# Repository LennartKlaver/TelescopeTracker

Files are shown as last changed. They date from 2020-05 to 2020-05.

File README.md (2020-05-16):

# TelescopeTracker

_**Please note: this is work in progress and not a finished product**_

The goal of this project is to make a telescope guiding camera work with PHD2 or alike by wifi.

My idea is to use the new Raspbery Pi HQ camera module and fit it into a 1.25inch eyepiece holder.
The camera can stream the video to the pc using the network, which can be converted to a virtual webcam device which we can open in PHD2.

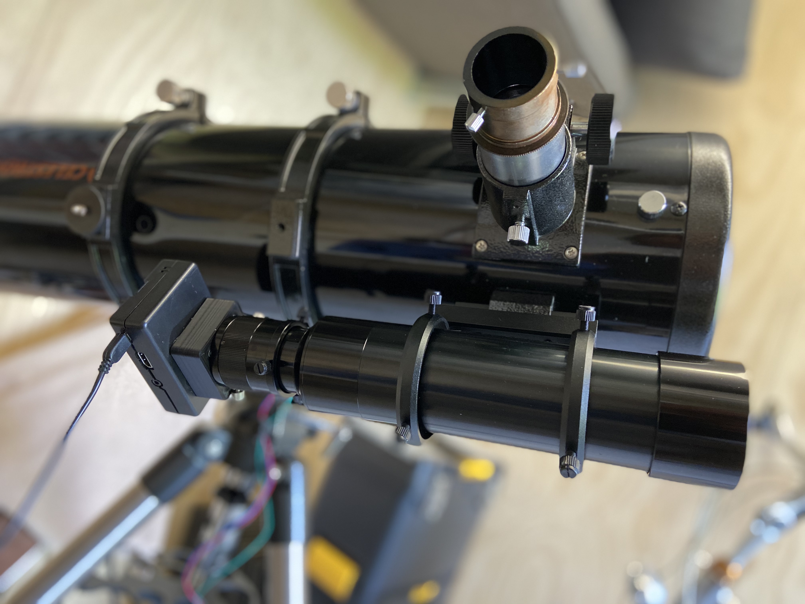
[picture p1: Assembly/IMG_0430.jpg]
Image of the telescope


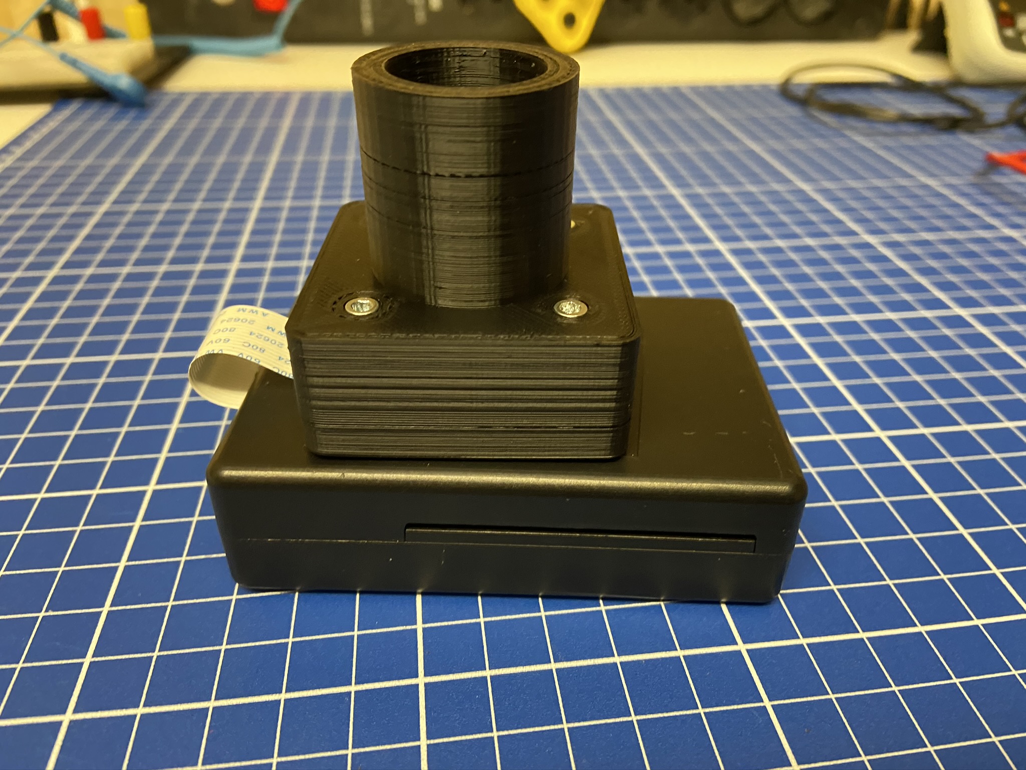
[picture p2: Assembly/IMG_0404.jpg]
Image of the camera assembly


# Parts
* A 3d printed camera mount for the eyepiece.
* A Raspberry Pi. https://www.raspberrypi.org/products/
* A nice casing to fit the raspberry in.
* A Raspberry Pi hq camera: https://www.raspberrypi.org/products/raspberry-pi-high-quality-camera/
* 4 M3x25 hexagon machine screw with cilinder head.
* 8 M3 nuts (I used self locking nuts to make sure they do not come loose).

# Instructions

## Assembly
1. Download the STL file and 3d print it.
2. From the camera, remove the small part that can be used to screw the cam on a mount. It is fixed by 2 hex bolts.
3. Check if the camera fits your print.
4. Place the printed part on top of the raspberry casing and mark the 4 holes.
	Please pick a spot where there are no components underneath (not to close to the usb ports).
	Also take note for the orientation of the ribbon cable. My casing had some room above the usb port so I guided the cable to that side.
5. Drill the mounting holes with a 3mm drill (remove the raspberry pi from the casing before drilling ... ).
6. Screw 4 M3x25 hexagon screws in the printed casing.
7. Push the camera module gently in its place. Sometimes it fits perfect, sometimes you have to turn the screws. Please apply proper ESD protection
8. Fixate the camera with 4 nuts..
9. Place the camera on top of the raspberry casing, do not forget the cable.
10. File a small gap to fit the ribbon cable inside the raspi casing.
11. Close the raspberry pi casing.
12. Place the camera on your telescope and power it up.

## Software
From here I assume you know a little bit about Raspberry Pi's. I used a headless setup and use SSH to communicate with the platform.
I connected the camera with my wifi and then used the steps below.
1. To enable the camera follow these steps: https://www.raspberrypi.org/documentation/usage/camera/
2. Check if the camera works by a call from the terminal: `raspistill -o testshot.jpg`
	Please note: if the image looks blurry, you need to focus the telescope/camera.
3. Install the RPi web interface for easy looking by browsing to the RasPi IP address: https://elinux.org/RPi-Cam-Web-Interface
	1. `sudo apt-get update`
	2. `sudo apt-get dist-upgrade`
	3. `sudo apt-get install git` 
	4. `git clone https://github.com/silvanmelchior/RPi_Cam_Web_Interface.git`
	5. `cd RPi_Cam_Web_Interface`
	6. `./install.sh`
	7. Browse to the Raspberry Pi's ip address and see the camera output.
	
To be continued....

# Development
## Finished
* Hardware design finished.
* Casing design finished.
* The camera mount fits the eyepiece.
* The camera works.
* The Raspberry Pi streams video with minimal delay.

## Next step
* Integrate the stream into windows cam system.

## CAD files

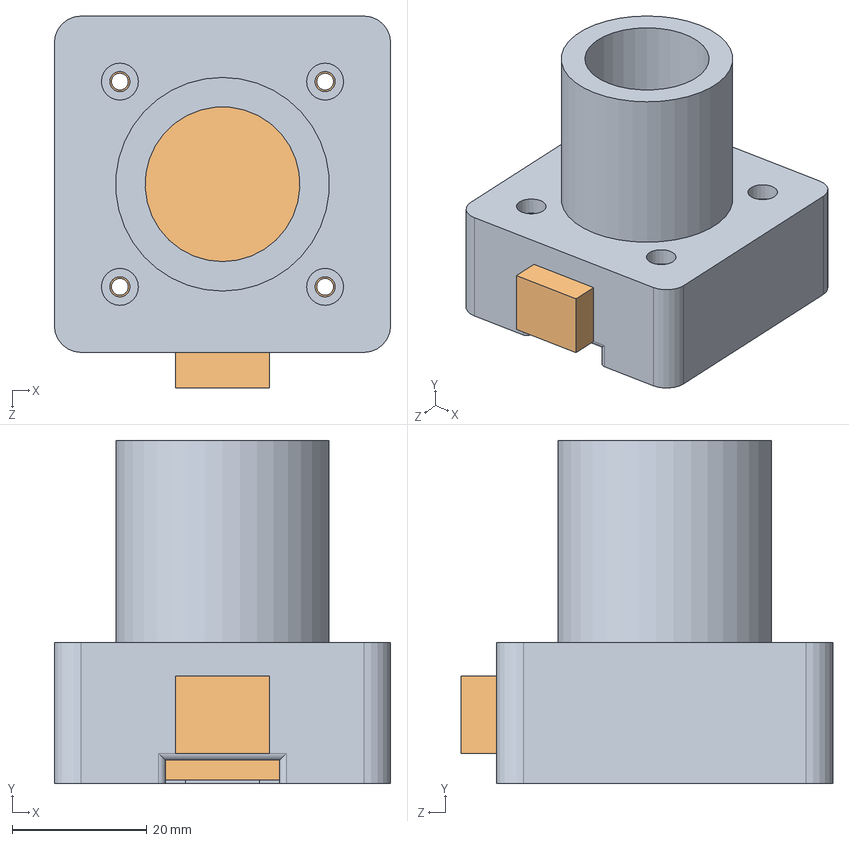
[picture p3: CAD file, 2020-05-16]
Camera mount/Assem1.SLDASM
50.0 x 51.0 x 55.3 mm
CamHolder
RaspiHDcamModel

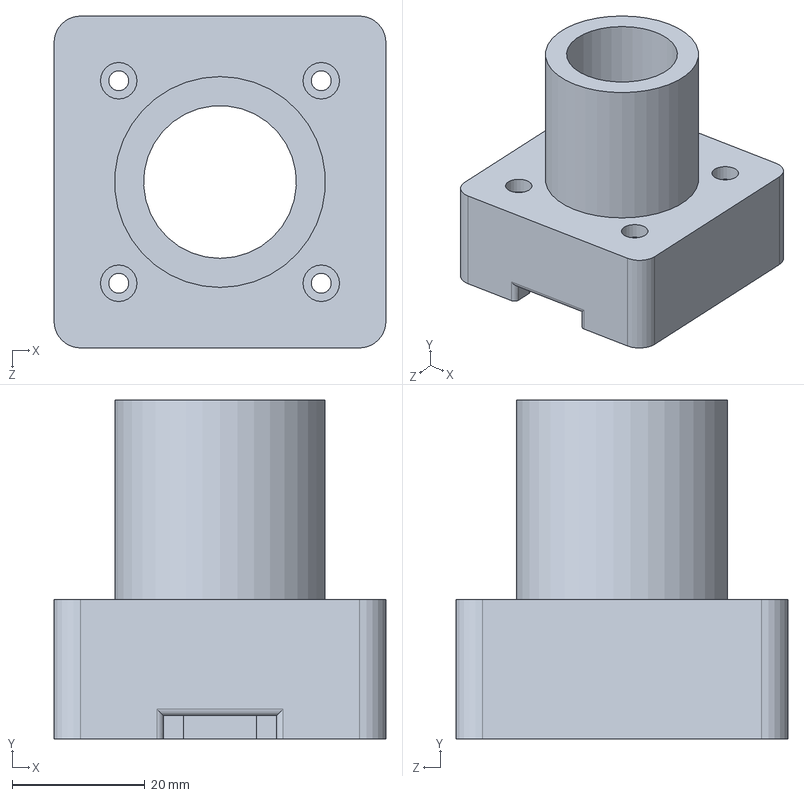
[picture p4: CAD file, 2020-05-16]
Camera mount/CamHolder.SLDPRT
50.0 x 51.0 x 50.0 mm

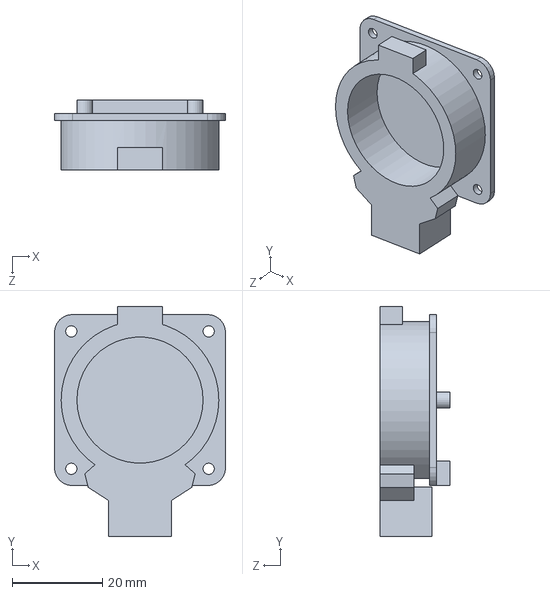
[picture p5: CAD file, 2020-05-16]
Camera mount/RaspiHDcamModel.SLDPRT
38.0 x 51.1 x 15.5 mm

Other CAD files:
Camera mount/CamHolder.SLDDRW
Camera mount/CamHolder.STL

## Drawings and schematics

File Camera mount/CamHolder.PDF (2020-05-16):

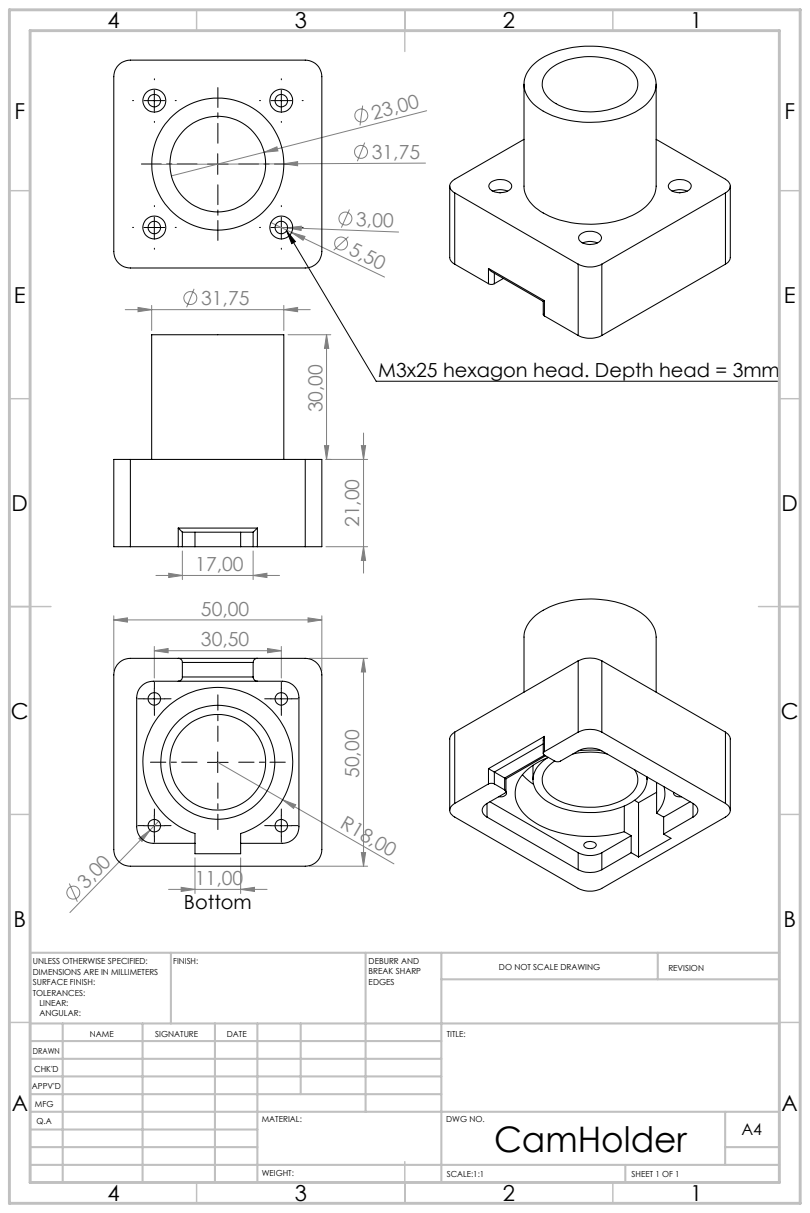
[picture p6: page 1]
FINISH:; DEBURR AND; BREAK SHARP; DO NOT SCALE DRAWING; REVISION; SCALE:1:1; SHEET 1 OF 1

M3x25 hexagon head. Depth head = 3mm

UNLESS OTHERWISE SPECIFIED:
DIMENSIONS ARE IN MILLIMETERS
SURFACE FINISH:
TOLERANCES:
LINEAR:
ANGULAR:

NAME | SIGNATURE | DATE | | | | TITLE:

DRAWN
CHK'D
APPV'D
MFG
Q.A | | | | MATERIAL: | DWG NO. CamHolder | A4

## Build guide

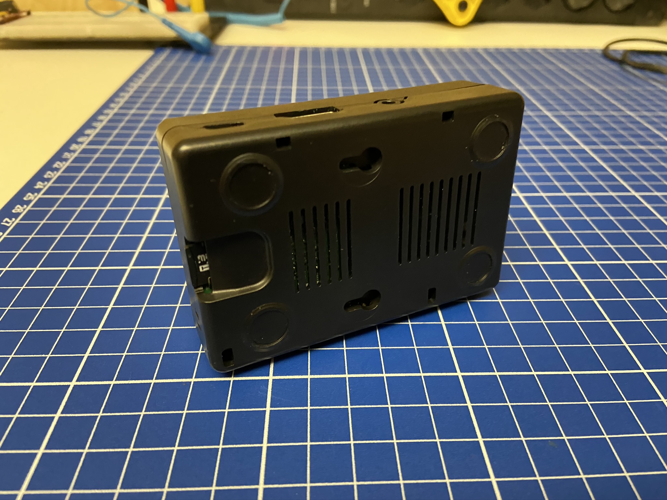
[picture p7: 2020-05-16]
Assembly/IMG_0406.jpg

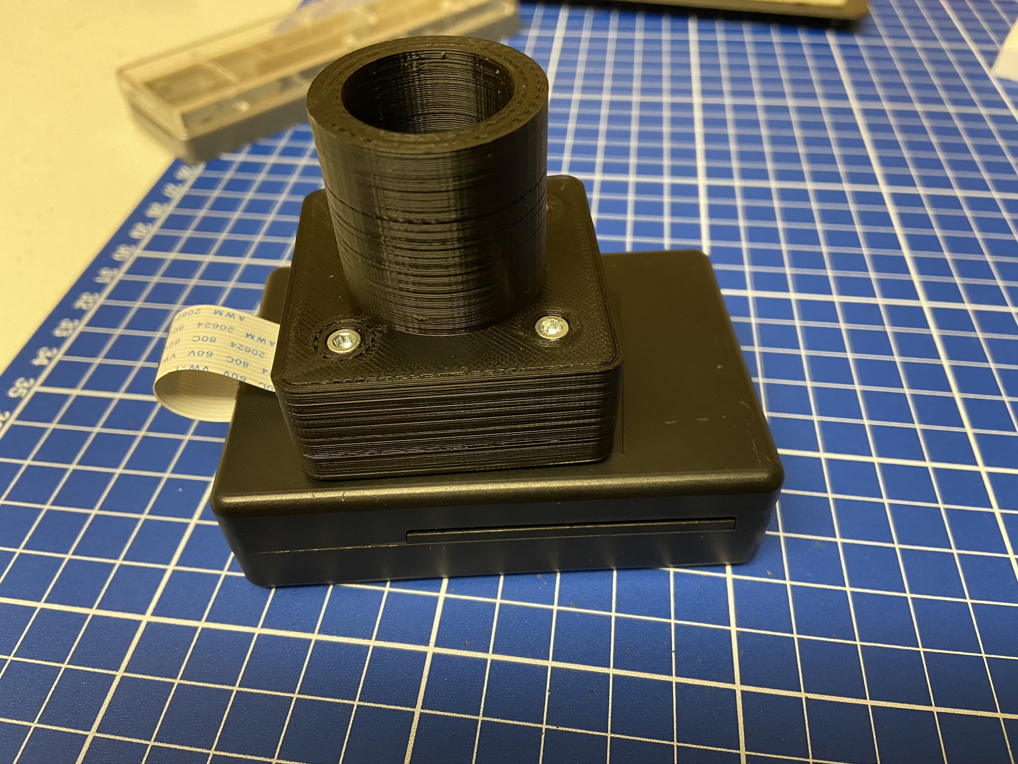
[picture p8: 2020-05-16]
Assembly/IMG_0400.jpg

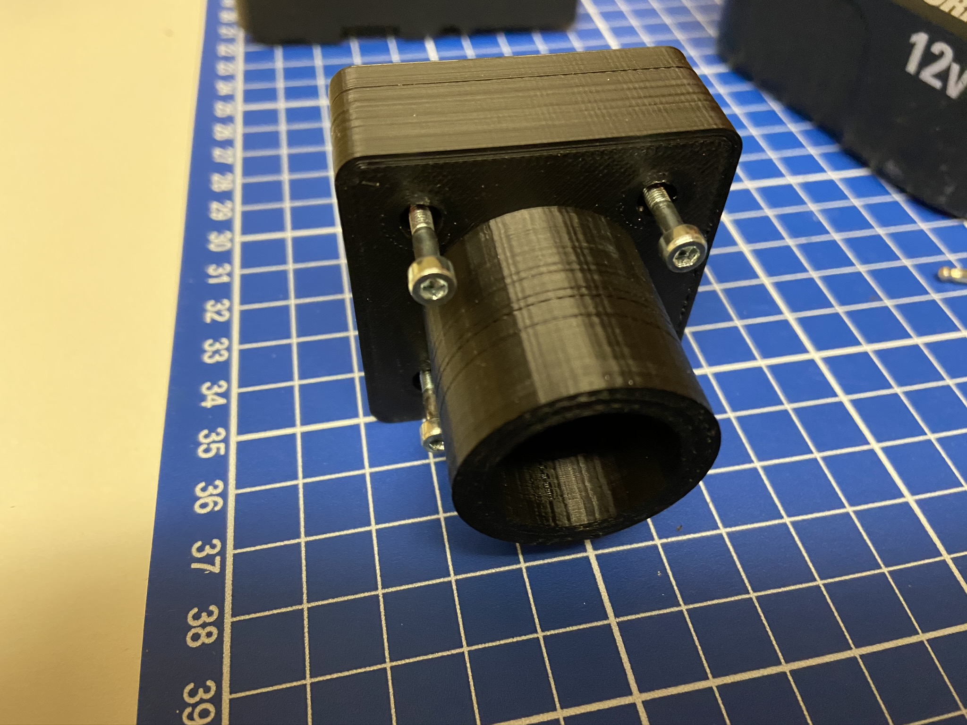
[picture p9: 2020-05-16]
Assembly/IMG_0393.jpg

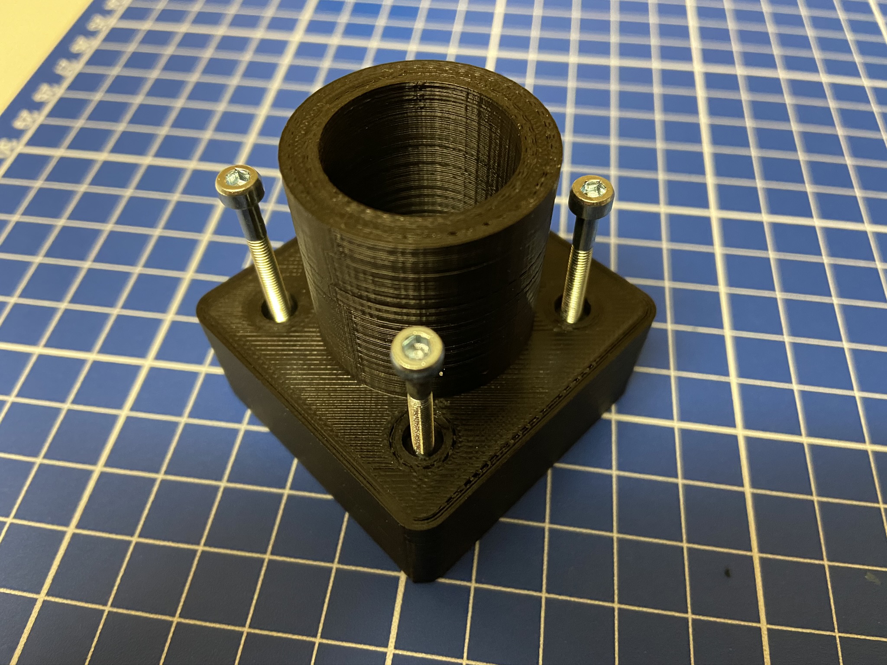
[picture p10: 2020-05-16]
Assembly/IMG_0388.jpg

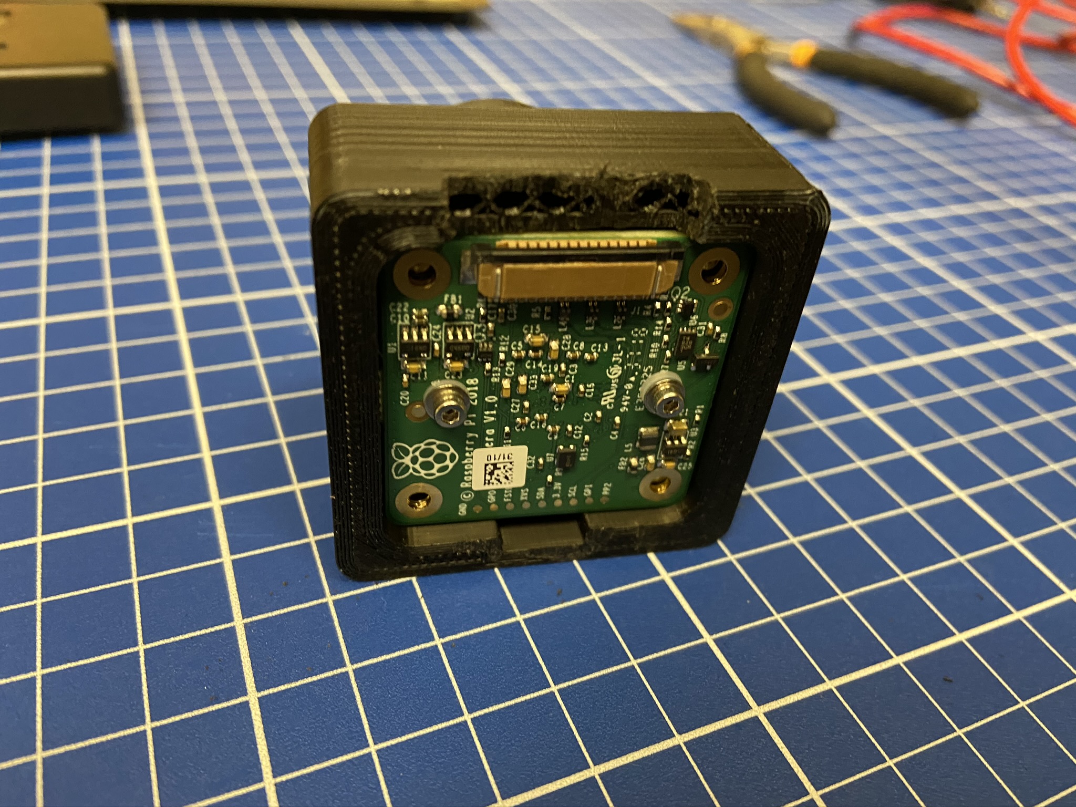
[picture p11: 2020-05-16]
Assembly/IMG_0397.jpg

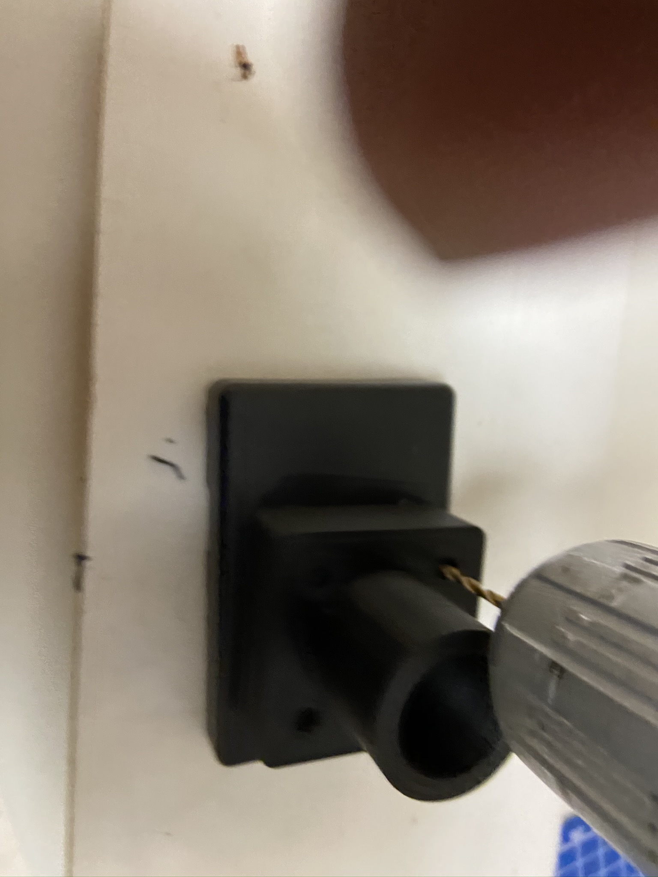
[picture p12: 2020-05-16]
Assembly/IMG_0390.jpg
